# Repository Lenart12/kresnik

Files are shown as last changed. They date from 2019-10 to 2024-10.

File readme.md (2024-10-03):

# Solar and Underfloor Heating Regulation Controller

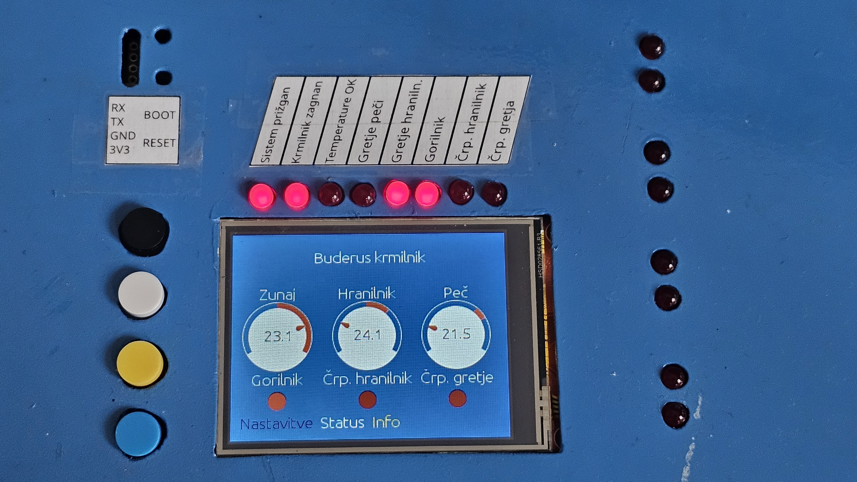
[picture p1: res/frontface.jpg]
frontface


## Overview

This project is a sophisticated heating system controller designed to manage up to 18 relays and 4 motors.
It utilizes DS18XXX temperature sensors for precise thermal regulation and offers WiFi capabilities for remote monitoring and control.
The system features an intuitive touchscreen interface along with physical buttons for ease of use.

Its core functionalities of this controller is managing a Buderus furnace and a domestic hot water (DHW) storage tank. By integrating with these components, the system ensures optimal heating efficiency and consistent hot water availability. The controller can intelligently switch between different heating modes, regulate the temperature of the furnace, and maintain the desired temperature in the DHW storage tank. This comprehensive control mechanism not only enhances comfort but also contributes to energy savings by optimizing the heating cycles and reducing unnecessary energy consumption.

## Project Structure

- **buderus-controller**: Contains the newest simplified controller.
- **esp32-HRC**: The older version of the project.
- **regulator board**: KiCAD PCB design project.

## Schema



## PCB Design



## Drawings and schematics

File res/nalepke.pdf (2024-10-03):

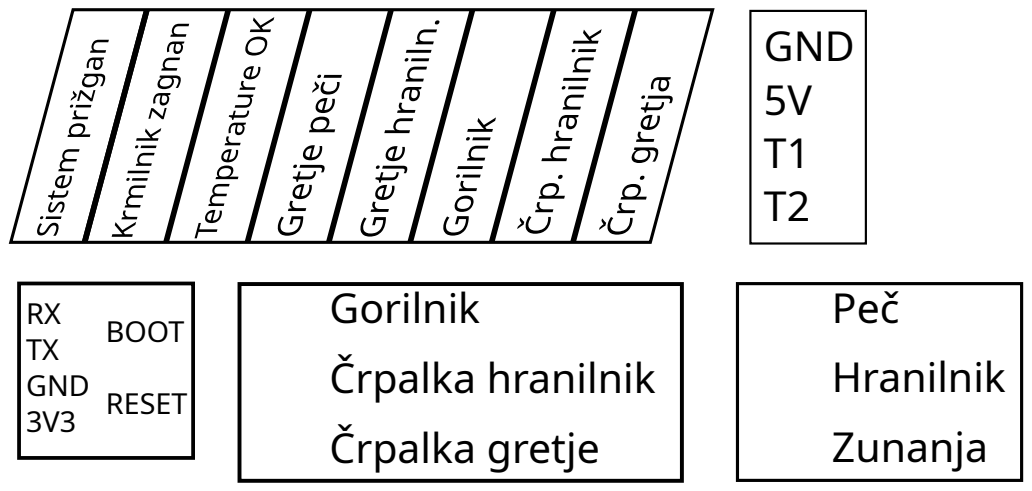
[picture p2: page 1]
RX TX GND 3V3; BOOT; RESET; Gorilnik Črpalka hranilnik Črpalka gretje; Peč Hranilnik Zunanja; GND 5V T1 T2

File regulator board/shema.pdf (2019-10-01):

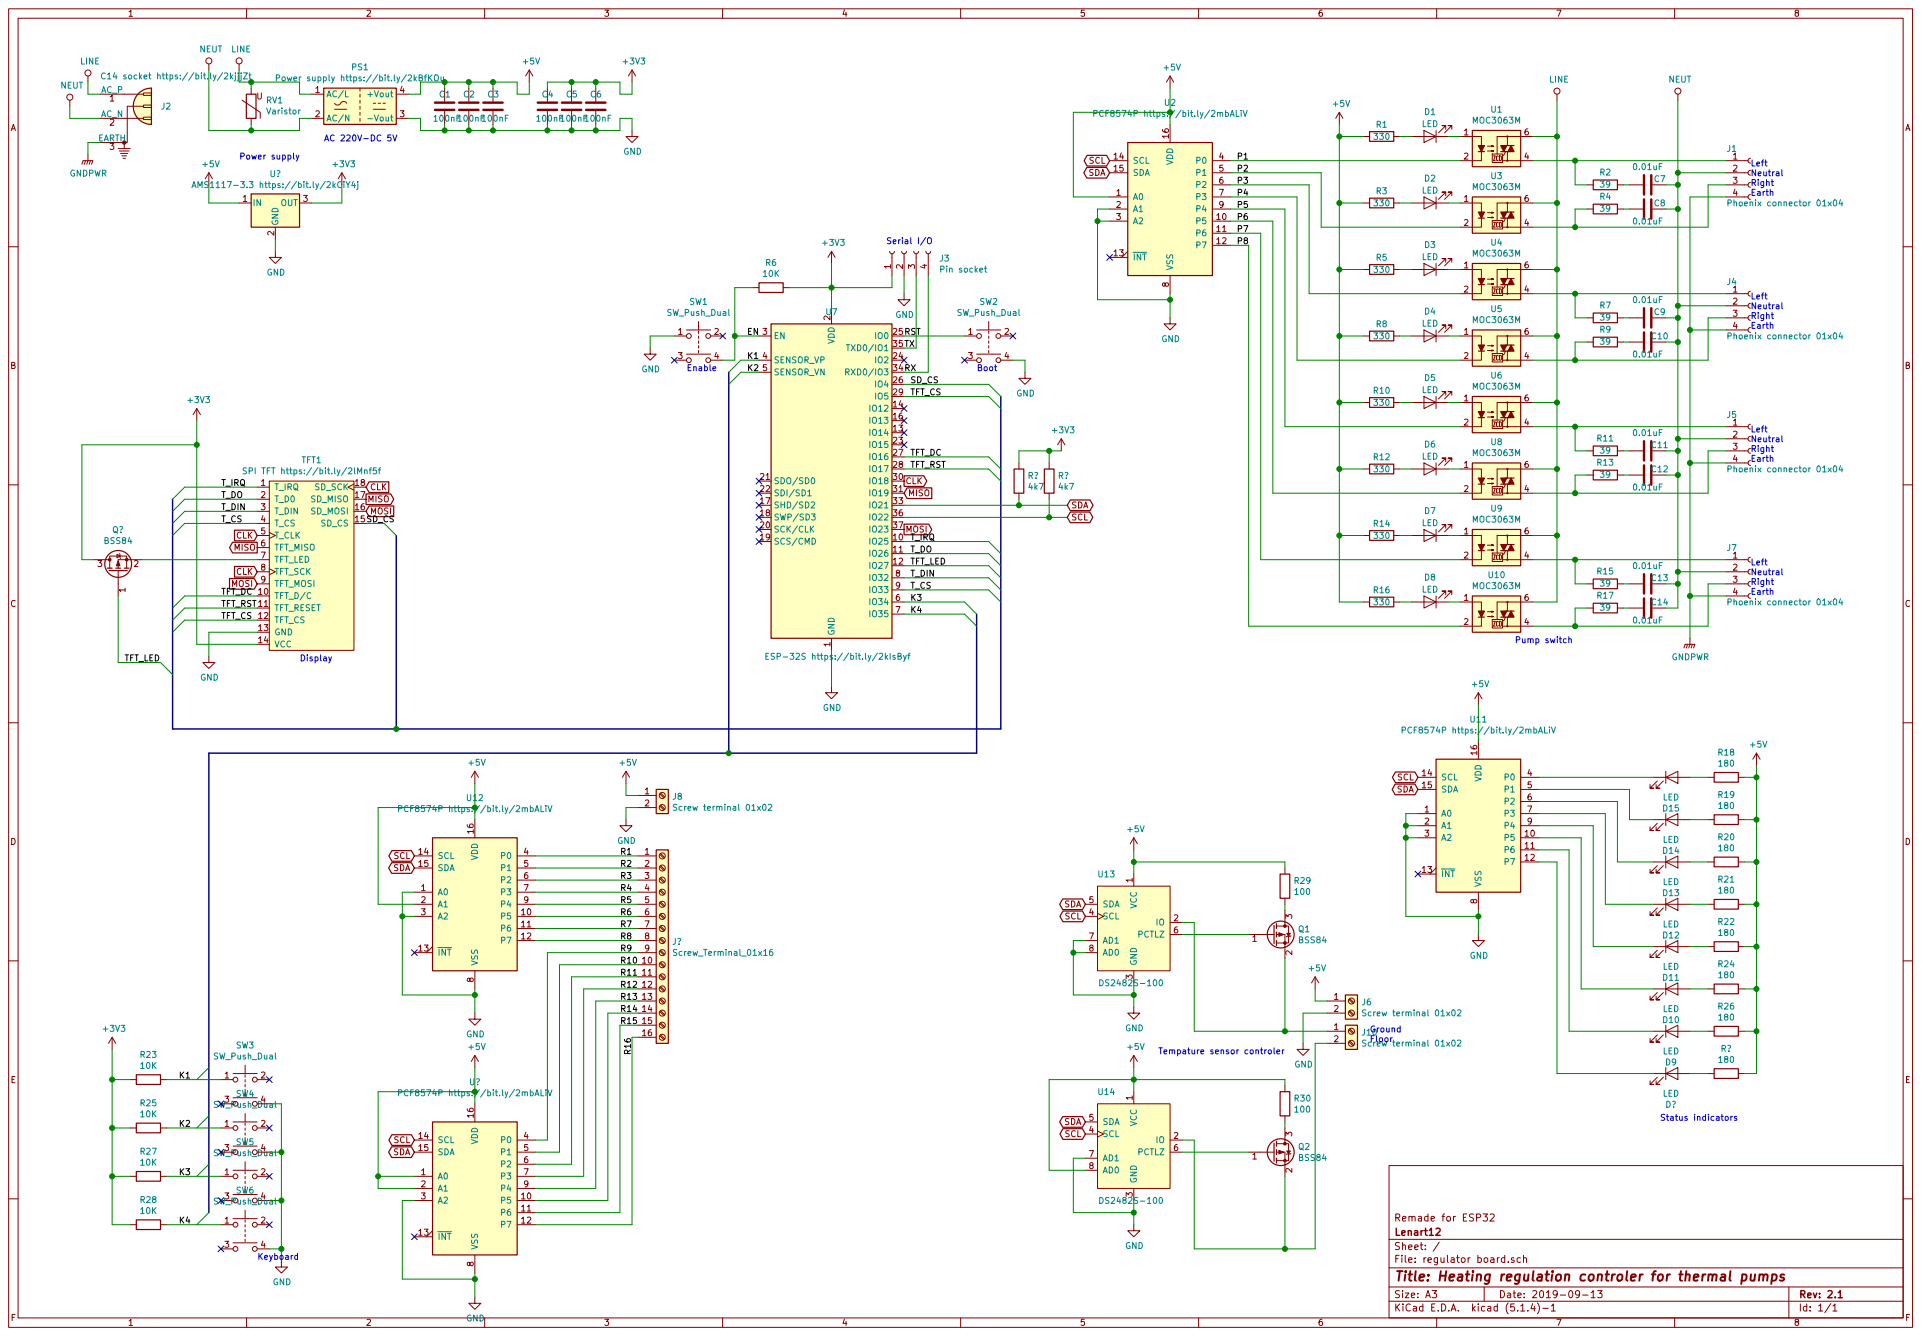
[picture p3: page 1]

LINE
J2 C14 socket https://bit.ly/2kjjjZt GNDPWR
NEUT

2 OUT 3 U? AMS1117-3.3 https://bit.ly/2kCiY4j +5V

2 SCK/CLK 20 SDO/SD0 21 SDI/SD1 22

SCL MOSI CLK MOSI MOSI
T_IRQ

8 P4 9 U12 PCF8574P https://bit.ly/2mbALiV GND

3 SCL 4 SDA 5 PCTLZ 6 AD1 7 AD0 8 U13DS2482S-100 GND

Ground Floor Tempature sensor controler

File: regulator board.sch Sheet: / Lenart12 Remade for ESP32

Id: 1/1 Title: Heating regulation controler for thermal pumps

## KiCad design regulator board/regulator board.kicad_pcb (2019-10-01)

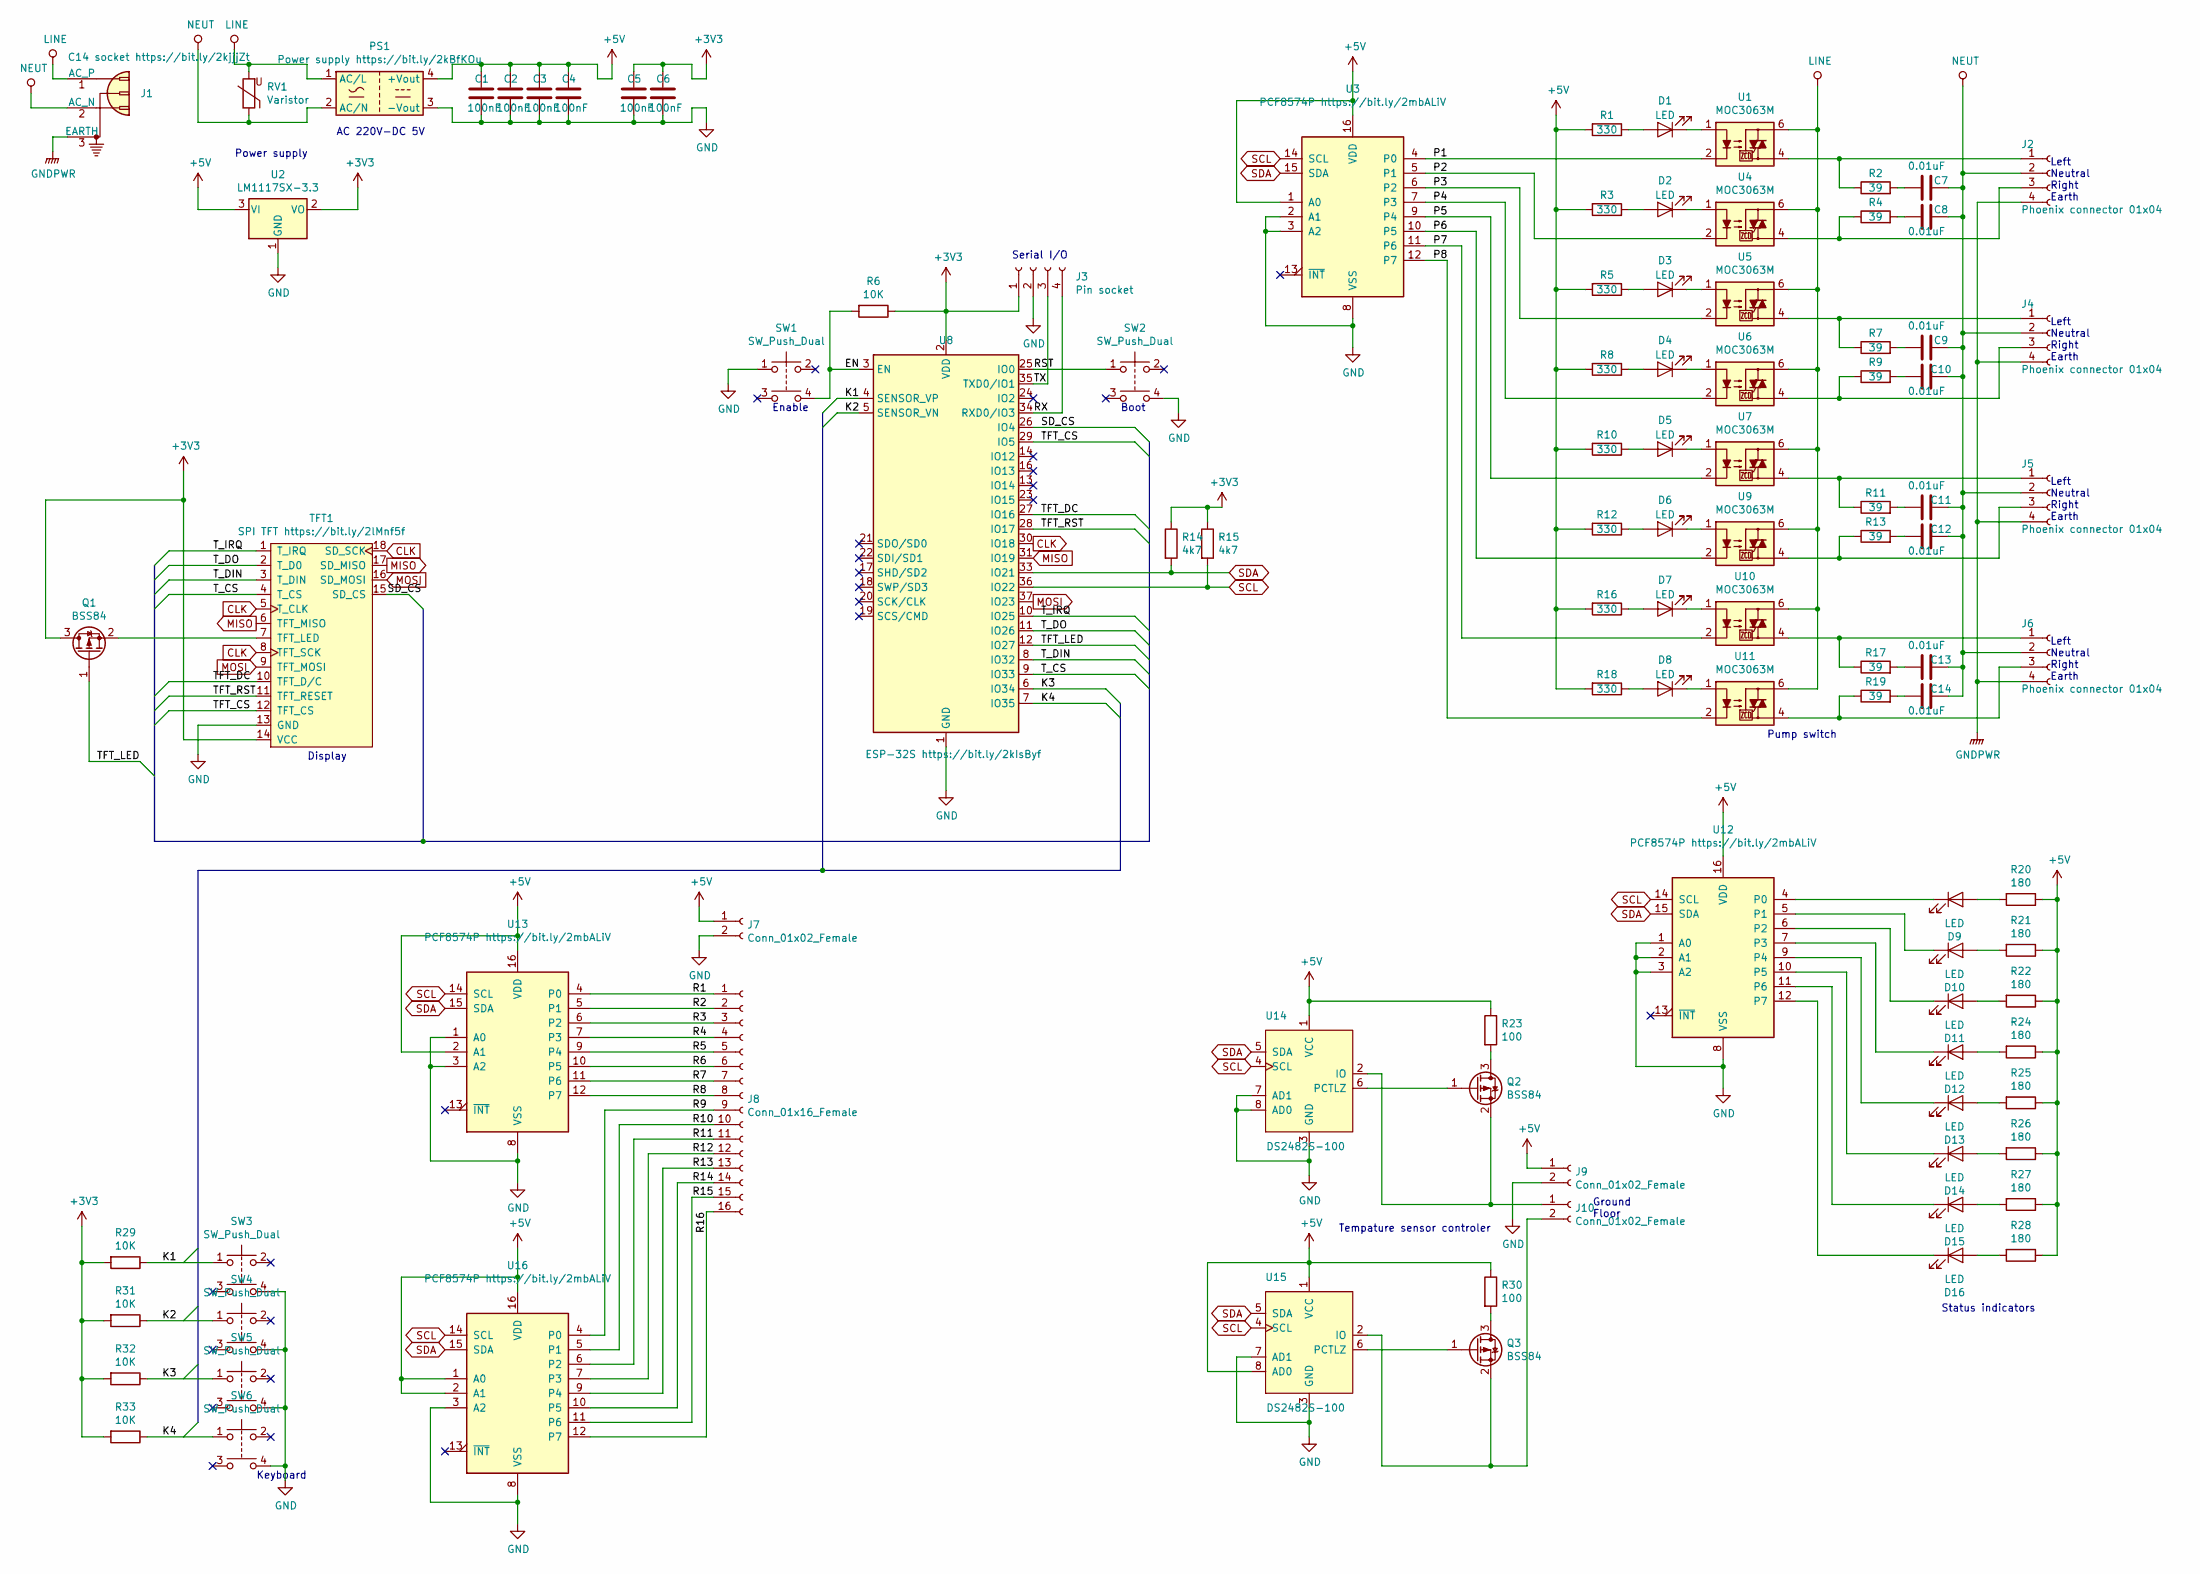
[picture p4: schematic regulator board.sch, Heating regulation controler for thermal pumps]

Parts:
C1, C2, C3, C4, C5, C6: 100nF; C_Rect_L7.0mm_W2.0mm_P5.00mm
C7, C8, C9, C10, C11, C12, C13, C14: 0.01uF; C_Rect_L18.0mm_W5.0mm_P15.00mm_FKS3_FKP3
D1, D2, D3, D4, D5, D6, D7, D8, D9, D10, D11, D12, D13, D14, D15, D16: LED; LED_D5.0mm
J1: C14 socket https://bit.ly/2kjjjZt; SolderWirePad_1x03_P5.715mm_Drill2mm
J2, J4, J5, J6: Phoenix connector 01x04; PhoenixContact_MSTBVA_2,5_4-G_1x04_P5.00mm_Vertical
J3: Pin socket; PinSocket_1x04_P2.54mm_Vertical
J7, J9, J10: Conn_01x02_Female; PinSocket_1x02_P2.54mm_Vertical
J8: Conn_01x16_Female; PinSocket_1x16_P2.54mm_Vertical
PS1: Power supply https://bit.ly/2kBfKOu; Converter_ACDC_HiLink_HLK-PMxx
Q1, Q2, Q3: BSS84; SOT-23
R1, R3, R5, R8, R10, R12, R16, R18: 330; R_Axial_DIN0204_L3.6mm_D1.6mm_P5.08mm_Horizontal
R2, R4, R7, R9, R11, R13, R17, R19: 39; R_Axial_DIN0204_L3.6mm_D1.6mm_P5.08mm_Horizontal
R6, R29, R31, R32, R33: 10K; R_Axial_DIN0204_L3.6mm_D1.6mm_P5.08mm_Horizontal
R14, R15: 4k7; R_Axial_DIN0204_L3.6mm_D1.6mm_P5.08mm_Horizontal
R20, R21, R22, R24, R25, R26, R27, R28: 180; R_Axial_DIN0204_L3.6mm_D1.6mm_P5.08mm_Horizontal
R23, R30: 100; R_Axial_DIN0204_L3.6mm_D1.6mm_P5.08mm_Horizontal
RV1: Varistor; RV_Disc_D12mm_W3.9mm_P7.5mm
SW1, SW2: SW_Push_Dual; SW_TH_Tactile_Omron_B3F-10xx
SW3, SW4, SW5, SW6: SW_Push_Dual; Push_E-Switch_KS01Q01
TFT1: SPI TFT https://bit.ly/2lMnf5f; SPI_TFT
U1, U4, U5, U6, U7, U9, U10, U11: MOC3063M; DIP-6_W7.62mm_Socket
U2: LM1117SX-3.3; TO-263-3_TabPin2
U3, U12, U13, U16: PCF8574P https://bit.ly/2mbALiV; DIP-16_W7.62mm
U8: ESP-32S https://bit.ly/2kIsByf; ESP32-WROOM-32
U14, U15: DS2482S-100; SOP-8_3.76x4.96mm_P1.27mm

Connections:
+3V3: C5.1, C6.1, J3.1, Q1.3 (D), R6.1, R14.1, R15.1, R29.2, R31.2, R32.2, R33.2, TFT1.14 (VCC), U2.2 (VO), U8.2 (VDD)
+5V: C1.1, C2.1, C3.1, C4.1, J7.1, J9.1, PS1.4 (+Vout), R1.2, R3.2, R5.2, R8.2, R10.2, R12.2, R16.2, R18.2, R20.1, R21.1, R22.1, R23.1, R24.1, R25.1, R26.1, R27.1, R28.1, R30.1, U2.3 (VI), U3.1 (A0), U3.16 (VDD), U12.16 (VDD), U13.2 (A1), U13.16 (VDD), U14.1 (VCC), U15.1 (VCC), U15.8 (AD0), U16.1 (A0), U16.2 (A1), U16.16 (VDD)
/EN: R6.2, SW1.4, U8.3 (EN)
/K1: R29.1, SW3.1, U8.4 (SENSOR_VP)
/K2: R31.1, SW4.1, U8.5 (SENSOR_VN)
/K3: R32.1, SW5.1, U8.6 (IO34)
/K4: R33.1, SW6.1, U8.7 (IO35)
/P1: U1.2, U3.4 (P0)
/P2: U3.5 (P1), U4.2
/P3: U3.6 (P2), U5.2
/P4: U3.7 (P3), U6.2
/P5: U3.9 (P4), U7.2
/P6: U3.10 (P5), U9.2
/P7: U3.11 (P6), U10.2
/P8: U3.12 (P7), U11.2
/R1: J8.1, U13.4 (P0)
/R2: J8.2, U13.5 (P1)
/R3: J8.3, U13.6 (P2)
/R4: J8.4, U13.7 (P3)
/R5: J8.5, U13.9 (P4)
/R6: J8.6, U13.10 (P5)
/R7: J8.7, U13.11 (P6)
/R8: J8.8, U13.12 (P7)
/R9: J8.9, U16.4 (P0)
/R10: J8.10, U16.5 (P1)
/R11: J8.11, U16.6 (P2)
/R12: J8.12, U16.7 (P3)
/R13: J8.13, U16.9 (P4)
/R14: J8.14, U16.10 (P5)
/R15: J8.15, U16.11 (P6)
/R16: J8.16, U16.12 (P7)
/RST: SW2.1, U8.25 (IO0)
/RX: J3.4, U8.34 (RXD0/IO3)
/SD_CS: TFT1.15 (SD_CS), U8.26 (IO4)
/TFT_CS: TFT1.12 (TFT_CS), U8.29 (IO5)
/TFT_DC: TFT1.10 (TFT_D/C), U8.27 (IO16)
/TFT_LED: Q1.1 (G), U8.12 (IO27)
/TFT_RST: TFT1.11 (TFT_RESET), U8.28 (IO17)
/TX: J3.3, U8.35 (TXD0/IO1)
/T_CS: TFT1.4 (T_CS), U8.9 (IO33)
/T_DIN: TFT1.3 (T_DIN), U8.8 (IO32)
/T_DO: TFT1.2 (T_D0), U8.11 (IO26)
/T_IRQ: TFT1.1 (T_IRQ), U8.10 (IO25)
CLK: TFT1.5 (T_CLK), TFT1.8 (TFT_SCK), TFT1.18 (SD_SCK), U8.30 (IO18)
GND: C1.2, C2.2, C3.2, C4.2, C5.2, C6.2, J3.2, J7.2, J9.2, PS1.3 (-Vout), SW1.1, SW2.4, SW3.4, SW4.4, SW5.4, SW6.4, TFT1.13 (GND), U2.1 (GND), U3.2 (A1), U3.3 (A2), U3.8 (VSS), U8.1 (GND), U8.15 (GND), U8.38 (GND), U12.1 (A0), U12.2 (A1), U12.3 (A2), U12.8 (VSS), U13.1 (A0), U13.3 (A2), U13.8 (VSS), U14.3 (GND), U14.7 (AD1), U14.8 (AD0), U15.3 (GND), U15.7 (AD1), U16.3 (A2), U16.8 (VSS)
GNDPWR: J1.3 (EARTH), J2.4, J4.4, J5.4, J6.4
LINE: J1.1 (AC_P), PS1.1 (AC/L), RV1.2, U1.6, U4.6, U5.6, U6.6, U7.6, U9.6, U10.6, U11.6
MISO: TFT1.6 (TFT_MISO), TFT1.17 (SD_MISO), U8.31 (IO19)
MOSI: TFT1.9 (TFT_MOSI), TFT1.16 (SD_MOSI), U8.37 (IO23)
NEUT: C7.1, C8.1, C9.1, C10.1, C11.1, C12.1, C13.1, C14.1, J1.2 (AC_N), J2.2, J4.2, J5.2, J6.2, PS1.2 (AC/N), RV1.1
unnamed: C7.2, R2.2
unnamed: C8.2, R4.2
unnamed: C9.2, R7.2
unnamed: C10.2, R9.2
unnamed: C11.2, R11.2
unnamed: C12.2, R13.2
unnamed: C13.2, R17.2
unnamed: C14.2, R19.2
unnamed: D1.1 (K), U1.1
unnamed: D1.2 (A), R1.1
unnamed: D2.1 (K), U4.1
unnamed: D2.2 (A), R3.1
unnamed: D3.1 (K), U5.1
unnamed: D3.2 (A), R5.1
unnamed: D4.1 (K), U6.1
unnamed: D4.2 (A), R8.1
unnamed: D5.1 (K), U7.1
unnamed: D5.2 (A), R10.1
unnamed: D6.1 (K), U9.1
unnamed: D6.2 (A), R12.1
unnamed: D7.1 (K), U10.1
unnamed: D7.2 (A), R16.1
unnamed: D8.1 (K), U11.1
unnamed: D8.2 (A), R18.1
unnamed: D9.1 (K), U12.4 (P0)
unnamed: D9.2 (A), R20.2
unnamed: D10.1 (K), U12.5 (P1)
unnamed: D10.2 (A), R21.2
unnamed: D11.1 (K), U12.6 (P2)
unnamed: D11.2 (A), R22.2
unnamed: D12.1 (K), U12.7 (P3)
unnamed: D12.2 (A), R24.2
unnamed: D13.1 (K), U12.9 (P4)
unnamed: D13.2 (A), R25.2
unnamed: D14.1 (K), U12.10 (P5)
unnamed: D14.2 (A), R26.2
unnamed: D15.1 (K), U12.11 (P6)
unnamed: D15.2 (A), R27.2
unnamed: D16.1 (K), U12.12 (P7)
unnamed: D16.2 (A), R28.2
unnamed: J2.1, R2.1, U1.4
unnamed: J2.3, R4.1, U4.4
unnamed: J4.1, R7.1, U5.4
unnamed: J4.3, R9.1, U6.4
unnamed: J5.1, R11.1, U7.4
unnamed: J5.3, R13.1, U9.4
unnamed: J6.1, R17.1, U10.4
unnamed: J6.3, R19.1, U11.4
unnamed: J10.1, Q2.2 (S), U14.2 (IO)
unnamed: J10.2, Q3.2 (S), U15.2 (IO)
unnamed: Q1.2 (S), TFT1.7 (TFT_LED)
unnamed: Q2.1 (G), U14.6 (PCTLZ)
unnamed: Q2.3 (D), R23.2
unnamed: Q3.1 (G), U15.6 (PCTLZ)
unnamed: Q3.3 (D), R30.2
SCL: R15.2, U3.14 (SCL), U8.36 (IO22), U12.14 (SCL), U13.14 (SCL), U14.4 (SCL), U15.4 (SCL), U16.14 (SCL)
SDA: R14.2, U3.15 (SDA), U8.33 (IO21), U12.15 (SDA), U13.15 (SDA), U14.5 (SDA), U15.5 (SDA), U16.15 (SDA)

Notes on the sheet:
Boot
Enable
Serial I/O
AC 220V-DC 5V
Left Neutral Right Earth
Status indicators
Display
Keyboard
Pump switch
Power supply
Tempature sensor controler
Ground Floor

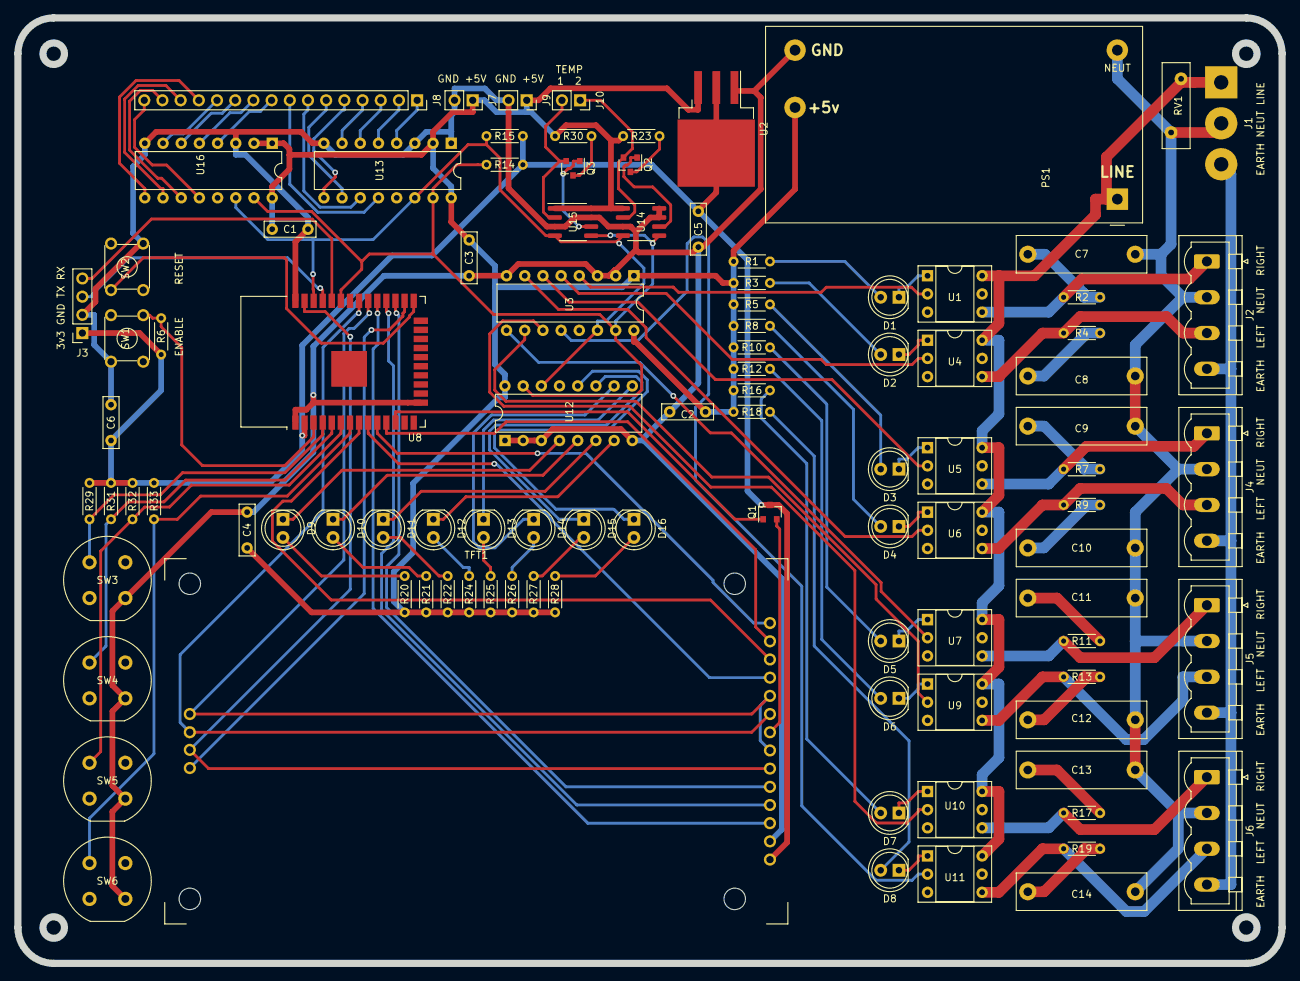
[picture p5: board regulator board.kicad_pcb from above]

Board: 2 copper layers, 176.5 x 132.0 mm, 101 parts (0 on the bottom side), 107 nets.

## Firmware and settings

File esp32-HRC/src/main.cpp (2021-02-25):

#include <Arduino.h>

#include <SPI.h>
#include <EEPROM.h>
#include <time.h>

#include <globals.h>

#include <indev_drivers.h>
#include <display_drivers.h>
#include <logging.h>
#include <tasks.h>
#include <lv_gui.h>

#include <mutex_util.h>

// Setup function
void setup(){
	// Start serial communication
	Serial.begin(115200);
	
	// Start littlevgl
	lv_init();
	lv_log_register_print_cb(logging_cb);

	// Initialize mutexes
	xSemaphoreGive(i2c_mutex);
	xSemaphoreGive(tempature_mutex);
	xSemaphoreGive(timing_mutex);

	for(uint8_t i = 0; i < 4; i++){
		xSemaphoreGive(motor_mutexes[i]);
	}
	LV_LOG_TRACE("Initialized mutexes");

	// Start display and I/O
	display_init();

	button_init();
	touchpad_init();

	// Start tick handler
	tick.attach_ms(LVGL_TICK_PERIOD, lv_tick_handler);
	LV_LOG_TRACE("Created tick handler");


	// Start expanders
	status_expander.begin(PCF8574_STATUS);
	status_expander.writeDDR(0xFF);
	thermo_expander.begin(PCF8574_THERMO);
	thermo_expander.writeDDR(0xFF);
	relay0_expander.begin(PCF8574_RELAY0);
	relay0_expander.writeDDR(0xFF);
	relay1_expander.begin(PCF8574_RELAY1);
	relay1_expander.writeDDR(0xFF);

	status_expander.digitalWrite(Status_led::power, ON);
	i2cLock();
	LV_LOG_TRACE("Started pcf8574 expanders");

	ds2482_0.setStrongPullup();
	ds2482_1.setStrongPullup();

	tempature_1.begin();
	tempature_2.begin();

	tempature_1.setWaitForConversion(false);
	tempature_2.setWaitForConversion(false);
	i2cUnlock();

	tempature_request_task(NULL);
	LV_LOG_TRACE("Started tempature sensors");

	// Load configuration
	EEPROM.begin(sizeof(config));
	#if CLEAN_CONFIG == 0
	EEPROM.get(0, config);
	config.control.load_default();
	EEPROM.put(0, config);
	EEPROM.commit();
	#else
	EEPROM.get(0, config);
	#endif
	LV_LOG_TRACE("Loaded configuration");

	// Start WiFi
	WiFi.begin(config.wifi_login.ssid, config.wifi_login.passwd);
	LV_LOG_TRACE("Started WiFi");


	// Start tasks
	lv_task_create(wifi_status_task, 1000, LV_TASK_PRIO_LOW, NULL);
	LV_LOG_TRACE("Created wifi status task");

	lv_task_create(time_display_task, 1000, LV_TASK_PRIO_LOWEST, NULL);
	LV_LOG_TRACE("Created time display task");

	lv_task_once(lv_task_create(tempature_request_task, 2000, LV_TASK_PRIO_MID, NULL));
	LV_LOG_TRACE("Measured tempature");

	request_temp_task_h = lv_task_create(tempature_request_task, 10000, LV_TASK_PRIO_MID, NULL);
	LV_LOG_INFO("Created tempature request task");

	screensaver_task_h = lv_task_create(screensaver_task, 1000, LV_TASK_PRIO_LOW, NULL);
	LV_LOG_TRACE("Created screensaver task");
	lv_task_create(tempature_shift_task, 60 * 60 * 1000, LV_TASK_PRIO_MID, NULL);
	LV_LOG_TRACE("Created tempature shift task");

	lv_task_create(control_minute_update_task, 60000, LV_TASK_PRIO_HIGH, NULL);
	LV_LOG_TRACE("Created control minute update task");

	config.control.setup();

	lv_main();
	WiFi.scanNetworks(true);

	LV_LOG_INFO("Setup complete");
}

// Loop function
void loop(){
	lv_task_handler();
	delay(1);
}

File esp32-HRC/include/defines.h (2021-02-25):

#ifndef DEFINES_H
#define DEFINES_H

#include <inttypes.h>
#include <lvgl.h>

#define CLEAN_CONFIG 0

#define SIM_TEMPATURE 1

// PINS {
static const uint8_t SD_CS = 4;     // 26

static const uint8_t TFT_LED = 27;  // 12
static const uint8_t TFT_DC = 16;   // 27
static const uint8_t TFT_RST = 17;  // 28
static const uint8_t TFT_CS = 5;    // 29


static const uint8_t SPI_CLK = 18;  // 30
static const uint8_t SPI_MISO = 19; // 31
static const uint8_t SPI_MOSI = 23;  // 37

static const uint8_t I2C_SDA = 21;  // 33
static const uint8_t I2C_SCL = 22;  // 36

static const uint8_t T_DIN = 32;    // 08
static const uint8_t T_CS = 33;     // 09
static const uint8_t T_IRQ = 25;    // 10
static const uint8_t T_DO = 26;     // 11

static const uint8_t BUTTON_0 = 36; // 04
static const uint8_t BUTTON_1 = 39; // 05
static const uint8_t BUTTON_2 = 34; // 06
static const uint8_t BUTTON_3 = 35; // 07

// }

// COLORS {
static const lv_color_t BUTTON_0_COLOR = LV_COLOR_MAKE(  0,   0,   0);
static const lv_color_t BUTTON_1_COLOR = LV_COLOR_MAKE(255, 255, 255);
static const lv_color_t BUTTON_2_COLOR = LV_COLOR_MAKE(255, 255,   0);
static const lv_color_t BUTTON_3_COLOR = LV_COLOR_MAKE(  0,   0, 255);

static const lv_color_t BUTTON_COLORS[]{
	BUTTON_0_COLOR,
	BUTTON_1_COLOR,
	BUTTON_2_COLOR,
	BUTTON_3_COLOR
};
// }

// TFT {
static const uint16_t W = 320;
static const uint16_t H = 240;
static const uint8_t TFT_ROTATION = 1;
static const uint32_t TFT_SCREEN_OFF = 30 * 1000; // 30 seconds

static const uint16_t TOUCH_CALIBRATION[5] = { 174, 3571, 311, 3539, 1 };

static const uint8_t LVGL_TICK_PERIOD = 20;
//}

// BUTTONS {
static const uint8_t BUTTONS[] = {
	BUTTON_0,
	BUTTON_1,
	BUTTON_2,
	BUTTON_3
};
// }

// ADDRESSES {
static const uint8_t DS2482_0 = 0x19;
static const uint8_t DS2482_1 = 0x18;
static const uint8_t PCF8574_STATUS = 0x20;
static const uint8_t PCF8574_THERMO = 0x21;
static const uint8_t PCF8574_RELAY0 = 0x22;
static const uint8_t PCF8574_RELAY1 = 0x23;
// }

// STATUS LEDS {
#define ON LOW
#define OFF HIGH

enum Status_led : uint8_t{
	power = 0,
	wifi = 1,
	moving_motor = 2,
	night_time_s = 3,
	burner_s = 4,
	hot_water_pump_s = 5,
	circulator_s = 6,
	error = 7
};
//}

// RELAY EXPANDER {
enum Relay_pin : uint8_t{
	burner = 0,
	hot_water_pump = 1,
	underfloor_pump_0 = 2,
	underfloor_pump_1 = 3,
	underfloor_pump_2 = 4,
	underfloor_pump_3 = 5,
	circulator_pump = 6,
	solar_pump = 7,
	inter_tank_pump = 8
};
//}

static const uint32_t CONTROL_INTERVAL = 2 * 60 * 1000; // 2 minutes
static const uint32_t CONVERSION_REQUEST_DELAY = 750;

static const int32_t NTP_OFFSET = 3600; // GMT+1
#endif

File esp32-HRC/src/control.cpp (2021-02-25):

#include <control.h>
#include <globals.h>
#include <mutex_util.h>
#include <tasks.h>
#include <EEPROM.h>

// Reads the tempature of the sensor
float TempatureAddress::read(){
    // Use the right expander
    DallasTemperature *tempature = (lane == 1) ? &tempature_1 : &tempature_2;

    i2cLock();
    // Read tempature
    float f = tempature->getTempC(address);
    i2cUnlock();

    return f;
}

// Reads the value of the relay expander
bool relayRead(uint8_t pin){;
    // Use the right expander
	PCF8574_WDDR *expander = (pin < 8) ? &relay0_expander : &relay1_expander;

    // Return the pin value
	return expander->digitalRead(pin % 8) == ON;
}

// Writes the value to the relay
void relayWrite(uint8_t pin, bool value){
    String log = ((value == true) ? "Opening" : "Closing") + (String)" relay " + pin;
    LV_LOG_INFO(log.c_str());

    // Set the status led for burner or pump
    if(pin == Relay_pin::burner) status_expander.digitalWrite(Status_led::burner_s, (value == true) ? ON : OFF);
    else if(pin == Relay_pin::hot_water_pump) status_expander.digitalWrite(Status_led::hot_water_pump_s, (value == true) ? ON : OFF);
    else if(pin == Relay_pin::circulator_pump) status_expander.digitalWrite(Status_led::circulator_s, (value == true) ? ON : OFF);

    // Use the right expander
	PCF8574_WDDR *expander = (pin < 8) ? &relay0_expander : &relay1_expander;

    // Set the pin
	expander->digitalWrite(pin % 8, (value == true) ? ON : OFF);
}

// Move the specified motor in the direction for a certain time
void move_motor(uint8_t motor, MotorDirection direction, uint32_t time_ms){
    // Try to move the motor for 10ms
    if( xSemaphoreTake(motor_mutexes[motor], 10 / portTICK_PERIOD_MS ) == pdTRUE ){
        String log = ((direction == MotorDirection::dir_open) ? "Opening" : "Closing") + (String)" motor " + motor + " for " + time_ms + "ms";
        LV_LOG_INFO(log.c_str());

        // Move the motor
        uint8_t dir = (direction == MotorDirection::dir_open) ? 0 : 1;
        thermo_expander.digitalWrite( motor * 2 + dir, ON);
        thermo_expander.digitalWrite( motor * 2 + (1 - dir), OFF);
        // Set the moving motor status led
        status_expander.digitalWrite(Status_led::moving_motor, ON);

        // Start the timer to turn off the motor
        motor_tickers[motor].once_ms(time_ms, stop_motor, motor);
    }
}

// Function that stops the specified motor
void stop_motor(uint8_t motor){
    // Turn off both motor directions 
    thermo_expander.digitalWrite(motor * 2, OFF);
    thermo_expander.digitalWrite(motor * 2 + 1, OFF);

    // Turn off the moving motor status led if no motor is moving
    status_expander.digitalWrite(Status_led::moving_motor, ( thermo_expander.read() != 0xFF) ? ON : OFF);

    String log = "Stopping motor " + (String)motor;
    LV_LOG_INFO(log.c_str());

    // Unlock the motors to move after two minutes
    motor_tickers[motor].once_ms(120000, unlockMutex, &motor_mutexes[motor]);
}

// Setup function for all the control related things
void Control::setup(){
    thermo_expander.write(0xFF);
    relay0_expander.write(0xFF);
    relay1_expander.write(0xFF);

    LV_LOG_INFO("Closing motors and reseting underfloor pumps");

    // Close all the motors and turn on/off all the pumps
    for(uint8_t i = 0; i < 4; i++){
        move_motor(i, MotorDirection::dir_close, 120000);
        relayWrite(Relay_pin::underfloor_pump_0 + i, underfloor_pump_enabled[i]);
    }

    // Turn off the circulator pump
    relayWrite(Relay_pin::circulator_pump, false);
}

// Update task
void Control::update(){
    // Read all the tempatures
    xSemaphoreTake(tempature_mutex, portMAX_DELAY);
    float boiler_tempature = boiler_temp[0];
    float hot_water_container_tempature = hot_water_container_temp[0];
    float enviroment_tempature = enviroment_temp[0];
    float underfloor_tempature[4];
    for(uint8_t i = 0; i < 4; i++){
        underfloor_tempature[i] = underfloor_temp[i][0];
    }
    float solar_collector_tempature = solar_collector_temp[0];
    float solar_tank_tempature = solar_tank_temp[0];
    float heat_exchanger_tempature = heat_exchanger_temp[0];
    xSemaphoreGive(tempature_mutex);

    static int i = 0;

    // Calculate tempature correction
    float underfloor_temp_correction = -(enviroment_tempature * tempature_slope);

    // Adjust for night time
    static bool night_time = false;
    if(night_time){
        underfloor_temp_correction -= night_time_correction;
    }

    // Log tempatures
    String tempatures = (String)i++ + ':' + (String)boiler_tempature + ' ' + hot_water_container_tempature + ' ' +
    enviroment_tempature + ' ' + underfloor_tempature[0] + ' '
	+ underfloor_tempature[1] + ' ' + underfloor_tempature[2] + ' '
    + underfloor_tempature[3] + ' ' + solar_collector_tempature + ' ' +
	solar_tank_tempature + ' ' + heat_exchanger_tempature + ' ' + underfloor_temp_correction;
    LV_LOG_TRACE(tempatures.c_str());

    // Turn on the boiler if it is required
    static bool need_for_heat = false;
    if(need_for_heat && burner_enabled && boiler_tempature < boiler_min_temp){
        config.burner_seconds++;
        if(relayRead(Relay_pin::burner) != true){
            LV_LOG_INFO("Boiler tempature too low - turning on");
            relayWrite(Relay_pin::burner, true);
        }
    }
    else if(boiler_tempature > boiler_max_temp){
        if(relayRead(Relay_pin::burner) != false){
            LV_LOG_INFO("Boiler tempature too high - turning off");
            relayWrite(Relay_pin::burner, false);
        }
        need_for_heat = false;
    }

    // Turn hot water pump on/off if required
    bool hwp_state = relayRead(Relay_pin::hot_water_pump);

    if(hot_water_pump_enabled && !hwp_state &&
        hot_water_container_tempature < hot_water_min_temp &&
        burner_enabled &&
        !night_time &&
        boiler_tempature > hot_water_container_tempature + 5.00f){
        LV_LOG_INFO("Hot water container tempature too low - turning on hwp and reseting underfloor pumps");
        for(int i = 0; i < 4; i++){
            relayWrite(Relay_pin::underfloor_pump_0 + i, false);
        }
        relayWrite(Relay_pin::hot_water_pump, true);
        hwp_state = true;
        need_for_heat = true;
    }
    else if(hwp_state && (hot_water_container_tempature > hot_water_max_temp || boiler_tempature - hot_water_container_tempature < 3.00f)){
        LV_LOG_INFO("Hot water container tempature too high - turning off and reseting underfloor pumps");
        relayWrite(Relay_pin::hot_water_pump, false);
        hwp_state = false;
        need_for_heat = false;
        for(int i = 0; i < 4; i++){
            relayWrite(Relay_pin::underfloor_pump_0 + i, underfloor_pump_enabled[i]);
        }
    }
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

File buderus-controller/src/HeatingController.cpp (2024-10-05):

/*
 * File: HeatingController.cpp
 * Lenart (c) 2024 koslenart@gmail.com 
 */


#include "defines.h"
#include "HeatingController.hpp"
#include "gui_helper.hpp"
#include "Preferences.h"

#ifdef SIMULATE_TEMPS
#include <stdlib.h>
#endif


void HeatingController::run() {
    load_settings();
    setup_devices();

    change_page(Page::Main);

    for (;;) {
        process_input();
        process_screen_timeout();
        _temp_0.Process();
        _temp_1.Process();

        #ifdef SIMULATE_TEMPS
        simulate_temps();
        #endif

        process_heating();
        if (_screen_on)
            (this->*_page_update)();
    }
}

void HeatingController::setup_devices() {
    // Serial
    Serial.begin(115200);

    // Setup TFT & Touch
    pinMode(TFT_LED_NEN, OUTPUT);
    digitalWrite(TFT_LED_NEN, LOW);

    _tft.init();
    _tft.setRotation(1);
    _tft.setTouch(TOUCH_CALIBRATION);
    _tft.fillScreen(TFT_BUDERUS_BLUE);
    _tft.setTextColor(TFT_WHITE, TFT_BUDERUS_BLUE, true);
    _tft.loadFont(Ubuntu_Regular18);
    _sprite.loadFont(Ubuntu_Regular18);

    _tft.setTextDatum(MC_DATUM);
    _tft.drawString("Zagon sistema...", _tft.width() / 2, _tft.height() / 2);

    // Buttons
    for (uint8_t i = 0; i < sizeof(BTN_PINS) / sizeof(BTN_PINS[0]); i++) {
        pinMode(BTN_PINS[i], INPUT);
    }

    // GPIO
    _pcf_led.begin();
    _pcf_relay.begin();

    for (int i = 0; i < 8; i++) {
        _pcf_led.pinMode(i, OUTPUT);
        _pcf_relay.pinMode(i, OUTPUT);
        _pcf_led.digitalWrite(i, HIGH);
        _pcf_relay.digitalWrite(i, HIGH);
    }

    // Setup temp sensors
    _temp_0.Process();
    _temp_1.Process();

    if (_temp_0.GetDeviceCount() + _temp_1.GetDeviceCount() != 3) {
        char buffer[50];
        sprintf(buffer, "Napaka pri inicializaciji senzorjev! %d+%d/3", _temp_0.GetDeviceCount(), _temp_1.GetDeviceCount());
        fatal_error(buffer);
    }

    #ifdef SIMULATE_TEMPS
    srand(millis());
    #endif

    // Finaly, turn on the power led
    set_status_led(StatusLed::PowerOn, true);
}

void HeatingController::process_input()
{
    if (_last_input != 0 && millis() - _last_input < 100) return;

    uint16_t x, y;
    if (_tft.getTouch(&x, &y)) {
        _last_input = millis();
        if (_input_locked) return;
        (this->*_on_touch)(x, y);
        _input_locked = true;
        return;
    }

    #define CHECK_BTN(pin, col) \
        if (digitalRead(BTN_##pin##_PIN) == LOW) { \
            _last_input = millis(); \
            if (_input_locked) return; \
            (this->*_on_btn_press)(Button::col); \
            _input_locked = true; \
            return; \
        }

    CHECK_BTN(B, Black)
    CHECK_BTN(W, White)
    CHECK_BTN(Y, Yellow)
    CHECK_BTN(C, Blue)

    _input_locked = false;
}

void HeatingController::fatal_error(const char *msg)
{
    set_screen_enabled(true);
    for (int i = 0; i < 8; i++) {
        _pcf_relay.digitalWrite(i, HIGH);
    }
    Serial.println(msg);
    _fatal_error_msg = msg;
    change_page(Page::FatalError);
    __unreachable();
}

void HeatingController::set_relay(Relay relay, bool state)
{
    switch (relay) {
        case Relay::FurnaceHeater:
            _heating_active = state;
            _pcf_relay.digitalWrite(0, !state);
            set_status_led(StatusLed::RelayFurnaceHeater, state);
            break;
        case Relay::DhwStoragePump:
            _storage_pump_active = state;
            _pcf_relay.digitalWrite(1, !state);
            set_status_led(StatusLed::RelayDhwStoragePump, state);
            break;
        case Relay::HeatingPump:
            _heating_circulation_active = state;
            _pcf_relay.digitalWrite(2, !state);
            set_status_led(StatusLed::RelayHeatingPump, state);
            break;
    }
    _gui_last_update = 0;
}

void HeatingController::set_status_led(StatusLed led, bool state)
{
    _pcf_led.digitalWrite(static_cast<uint8_t>(led), !state);

    // Special case for state leds, only one can be on at a time
    if (state == true) {
        switch (led)
        {
            case StatusLed::StateIdle:
                _pcf_led.digitalWrite(static_cast<uint8_t>(StatusLed::StateHeatingFurnace), HIGH);
                _pcf_led.digitalWrite(static_cast<uint8_t>(StatusLed::StateHeatingDhwStorage), HIGH);
                break;
            case StatusLed::StateHeatingFurnace:
                _pcf_led.digitalWrite(static_cast<uint8_t>(StatusLed::StateIdle), HIGH);
                _pcf_led.digitalWrite(static_cast<uint8_t>(StatusLed::StateHeatingDhwStorage), HIGH);
                break;
            case StatusLed::StateHeatingDhwStorage:
                _pcf_led.digitalWrite(static_cast<uint8_t>(StatusLed::StateIdle), HIGH);
                _pcf_led.digitalWrite(static_cast<uint8_t>(StatusLed::StateHeatingFurnace), HIGH);
                break;
        }
    }
}

float HeatingController::get_temp(uint8_t sensor_id)
{
    #ifndef SIMULATE_TEMPS
    if (sensor_id > 2) return NAN;
    if (sensor_id >= _temp_0.GetDeviceCount()) {
        if (_temp_1.GetLastReadMillis() == 0) return NAN;
        return _temp_1.GetTemperatureC(sensor_id - _temp_0.GetDeviceCount());
    }
    if (_temp_0.GetLastReadMillis() == 0) return NAN;
    return _temp_0.GetTemperatureC(sensor_id);
    #else
    if (sensor_id == _sensor_furnace_id) return _sim_temp_furnace;
    if (sensor_id == _sensor_dhw_storage_id) return _sim_temp_dhw_storage;
    if (sensor_id == _sensor_outside_id) return _sim_temp_outside;
    return NAN;
    #endif
}

#ifdef SIMULATE_TEMPS

void HeatingController::simulate_temps() {
    if (_last_sim_update != 0 && millis() - _last_sim_update < 1000) return;
    _last_sim_update = millis();

    const bool sim_runaway_furnace = false;

    // Outside not changing

    // Furnace temp cools down if not heating
    if (_heating_active || sim_runaway_furnace) {
        _sim_temp_furnace += 1 + rand() % 10 / 10.0;
    } else {
        _sim_temp_furnace -= rand() % 5 / 10.0;
    }

    // Storage temp cools down
    _sim_temp_dhw_storage -= rand() % 5 / 10.0;

    // Furnace cools down faster if circulation pump is on
    if (_heating_circulation_active) {
        _sim_temp_furnace -= rand() % 10 / 10.0;
    }

    // If dhw storage pump is on, storage temp and furnace temp will slowly equalize
    if (_storage_pump_active) {
        float dT = _sim_temp_furnace - _sim_temp_dhw_storage;
        if (dT > 0) {
            _sim_temp_furnace -= dT / 10;
            _sim_temp_dhw_storage += dT / 10;
        } else {
            _sim_temp_furnace += dT / 10;
            _sim_temp_dhw_storage -= dT / 10;
        }
    }
}

#endif
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

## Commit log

2019-02-23 display pcb
    [display-B.Cu.gbr, display-B.Mask.gbr, display-B.Paste.gbr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]
2019-02-23 rst pin for nano
    [optocupler-B.Cu.gbr, optocupler-B.Mask.gbr, optocupler-B.SilkS.gbr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]
2019-02-23 update pcb
    [display-B.Cu.gbr, display-B.Mask.gbr, display-B.Paste.gbr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]
2019-09-15 Single PCB scheme
    [display-B.Cu.gbr, display-B.Mask.gbr, display-B.Paste.gbr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]
2020-03-08 Display and input drivers
2020-03-10 status led improvement
2020-03-10 burner + valve control fix
    [control.cpp]
2020-06-12 Fixed I2C race conditions
    [control.cpp, main.cpp]
2020-06-12 Manual motor control, changed NTPClient library to built in time.h library + bug fixes
    [control.cpp, defines.h, lv_gui.cpp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]
2024-10-05 feat: Allow instant heating state transtitions in heating control loop
2024-10-05 rework: Improve GUI to use smooth fonts and add temp gauges on main screen
    [HeatingController.cpp, HeatingController.hpp, Main.cpp]
